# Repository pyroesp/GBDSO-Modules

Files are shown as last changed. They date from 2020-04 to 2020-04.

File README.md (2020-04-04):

# GBDSO Modules

This repository will include one or more schematics and PCBs based on the [GBDSO repository](https://github.com/pyroesp/GBDSO).  
In here I'll be making modules of the GBDSO schematic so that I can test them individually.  

A motherboard PCB will also be made so that all modules can be attached to each other and tested as a whole.  

Not sure yet how I'm going to set this up, but I'd like to keep everything related to the modules and motherboard in this repository.

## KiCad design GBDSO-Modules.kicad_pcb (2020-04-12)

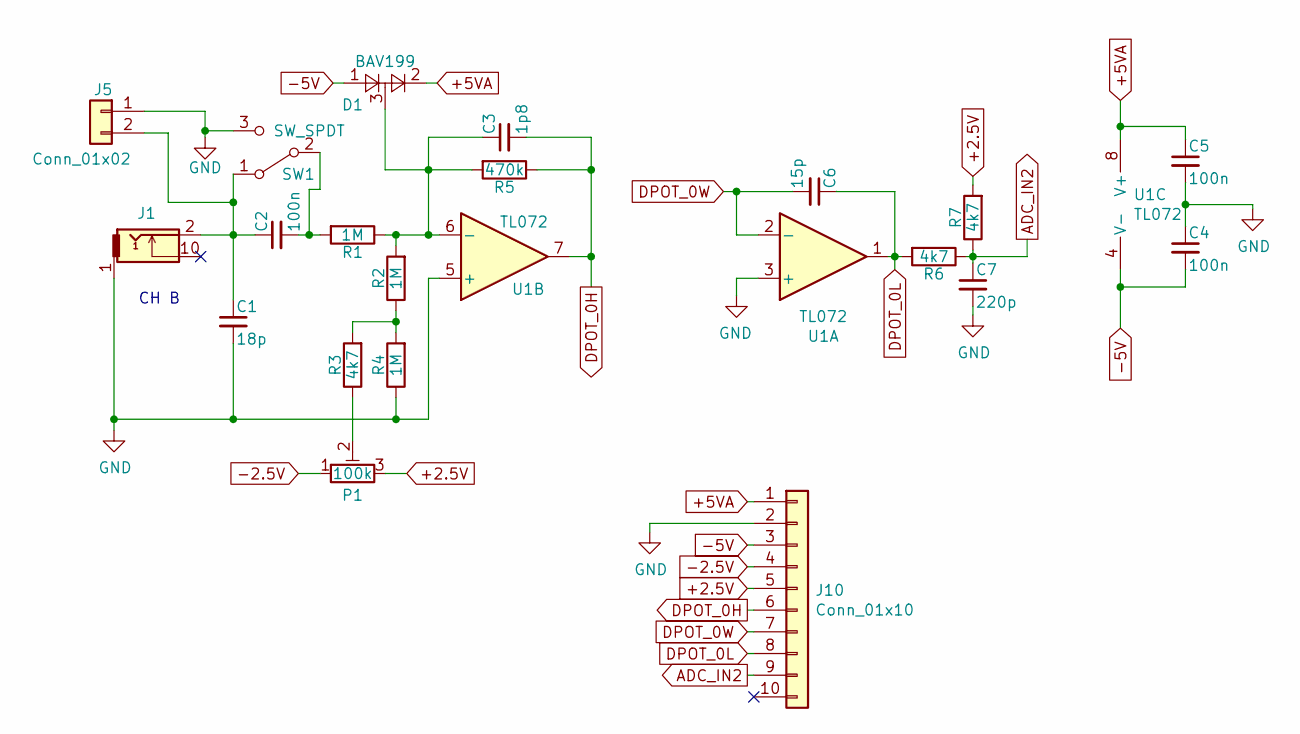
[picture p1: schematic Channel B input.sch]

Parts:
C1: 18p; C_0805_2012Metric
C2, C4, C5: 100n; C_0805_2012Metric
C3: 1p8; C_0805_2012Metric
C6: 15p; C_0805_2012Metric
C7: 220p; C_0805_2012Metric
D1: BAV199; SOT-23_Handsoldering
J1: MJ-3523-SMT-TR
J5: Conn_01x02; PinHeader_1x02_P2.54mm_Horizontal
J10: Conn_01x10; DIP-10_W10.16mm
P1: 100k; Potentiometer_Vishay_TS53YJ_Vertical
R1, R2, R4: 1M; R_0805_2012Metric
R3, R6, R7: 4k7; R_0805_2012Metric
R5: 470k; R_0805_2012Metric
SW1: SW_SPDT; SW_SPDT_CK-JS102011SAQN
U1: TL072; SOIC-8_3.9x4.9mm_P1.27mm

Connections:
+2.5V: J10.5, P1.3, R7.2; also elsewhere on the board
+5VA: C5.1, D1.2, J10.1, U1.8 (V+); also elsewhere on the board
-2.5V: J10.4, P1.1; also elsewhere on the board
-5V: C4.2, D1.1, J10.3, U1.4 (V-); also elsewhere on the board
ADC_IN2: C7.1, J10.9, R6.1, R7.1; also elsewhere on the board
DPOT_0H: C3.2, J10.6, R5.1, U1.7; also elsewhere on the board
DPOT_0L: C6.1, J10.8, R6.2, U1.1; also elsewhere on the board
DPOT_0W: C6.2, J10.7, U1.2 (-); also elsewhere on the board
GND: C1.2, C4.1, C5.2, C7.2, J1.1, J5.1, J10.2, R4.1, SW1.3 (C), U1.3 (+), U1.5 (+); also elsewhere on the board
unnamed: C1.1, C2.1, J1.2, J5.2, SW1.1 (A)
unnamed: C2.2, R1.2, SW1.2 (B)
unnamed: C3.1, D1.3, R1.1, R2.2, R5.2, U1.6 (-)
unnamed: P1.2, R3.1
unnamed: R2.1, R3.2, R4.2

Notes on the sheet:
CH B

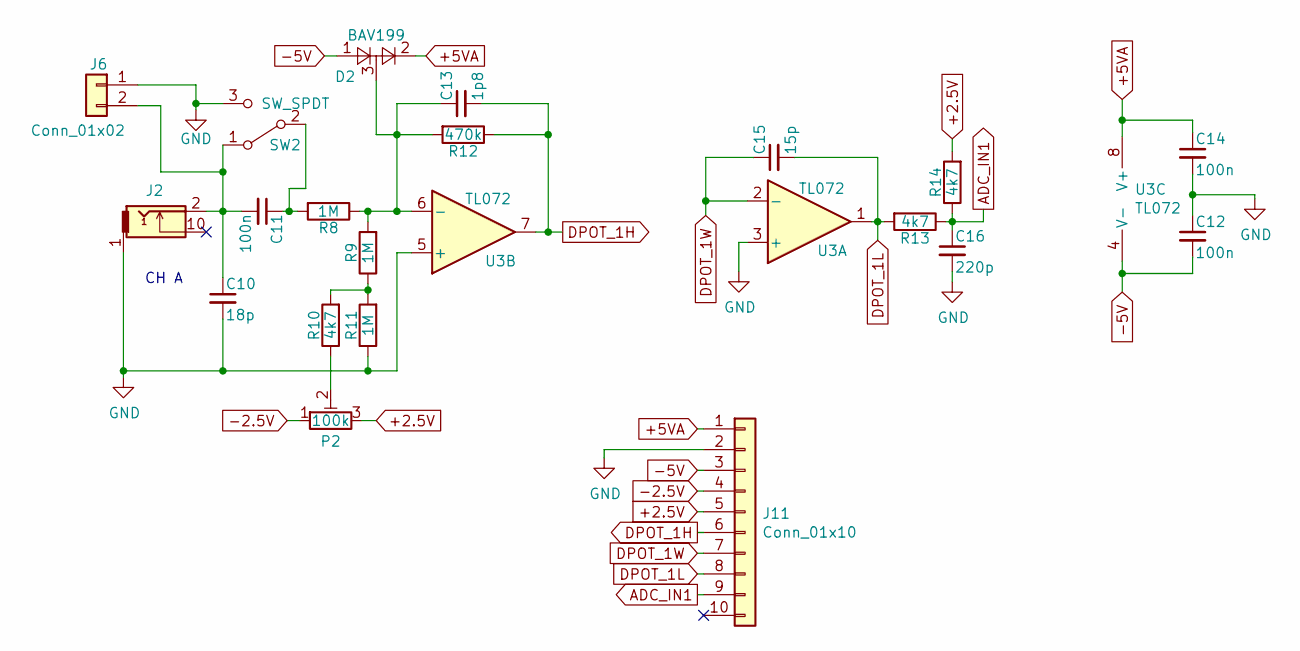
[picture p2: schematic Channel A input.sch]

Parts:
C10: 18p; C_0805_2012Metric
C11, C12, C14: 100n; C_0805_2012Metric
C13: 1p8; C_0805_2012Metric
C15: 15p; C_0805_2012Metric
C16: 220p; C_0805_2012Metric
D2: BAV199; SOT-23_Handsoldering
J2: MJ-3523-SMT-TR
J6: Conn_01x02; PinHeader_1x02_P2.54mm_Horizontal
J11: Conn_01x10; DIP-10_W10.16mm
P2: 100k; Potentiometer_Vishay_TS53YJ_Vertical
R8, R9, R11: 1M; R_0805_2012Metric
R10, R13, R14: 4k7; R_0805_2012Metric
R12: 470k; R_0805_2012Metric
SW2: SW_SPDT; SW_SPDT_CK-JS102011SAQN
U3: TL072; SOIC-8_3.9x4.9mm_P1.27mm

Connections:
+2.5V: J11.5, P2.3, R14.2; also elsewhere on the board
+5VA: C14.1, D2.2, J11.1, U3.8 (V+); also elsewhere on the board
-2.5V: J11.4, P2.1; also elsewhere on the board
-5V: C12.2, D2.1, J11.3, U3.4 (V-); also elsewhere on the board
ADC_IN1: C16.1, J11.9, R13.1, R14.1; also elsewhere on the board
DPOT_1H: C13.2, J11.6, R12.1, U3.7; also elsewhere on the board
DPOT_1L: C15.2, J11.8, R13.2, U3.1; also elsewhere on the board
DPOT_1W: C15.1, J11.7, U3.2 (-); also elsewhere on the board
GND: C10.2, C12.1, C14.2, C16.2, J2.1, J6.1, J11.2, R11.1, SW2.3 (C), U3.3 (+), U3.5 (+); also elsewhere on the board
unnamed: C10.1, C11.2, J2.2, J6.2, SW2.1 (A)
unnamed: C11.1, R8.2, SW2.2 (B)
unnamed: C13.1, D2.3, R8.1, R9.2, R12.2, U3.6 (-)
unnamed: P2.2, R10.1
unnamed: R9.1, R10.2, R11.2

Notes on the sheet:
CH A

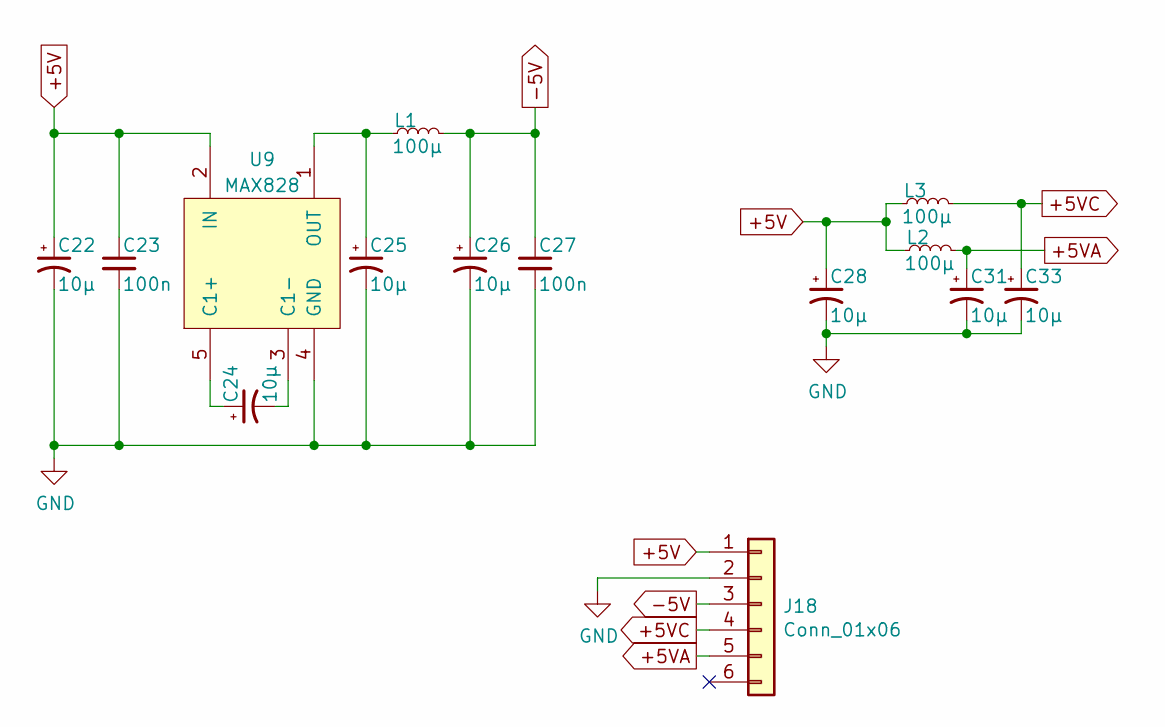
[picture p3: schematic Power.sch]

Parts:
C22, C24, C25, C26, C28, C31, C33: 10µ; C_1206_3216Metric
C23, C27: 100n; C_0805_2012Metric
J18: Conn_01x06; DIP-6_W7.62mm
L1, L2, L3: 100µ; L_0805_2012Metric_Pad1.15x1.40mm_HandSolder
U9: MAX828; SOT-23-5_HandSoldering

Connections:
+5V: C22.1, C23.1, C28.1, J18.1, L2.1, L3.1, U9.2 (IN); also elsewhere on the board
+5VA: C31.1, J18.5, L2.2; also elsewhere on the board
+5VC: C33.1, J18.4, L3.2; also elsewhere on the board
-5V: C26.1, C27.1, J18.3, L1.2; also elsewhere on the board
GND: C22.2, C23.2, C25.2, C26.2, C27.2, C28.2, C31.2, C33.2, J18.2, U9.4 (GND); also elsewhere on the board
unnamed: C24.1, U9.5 (C1+)
unnamed: C24.2, U9.3 (C1-)
unnamed: C25.1, L1.1, U9.1 (OUT)

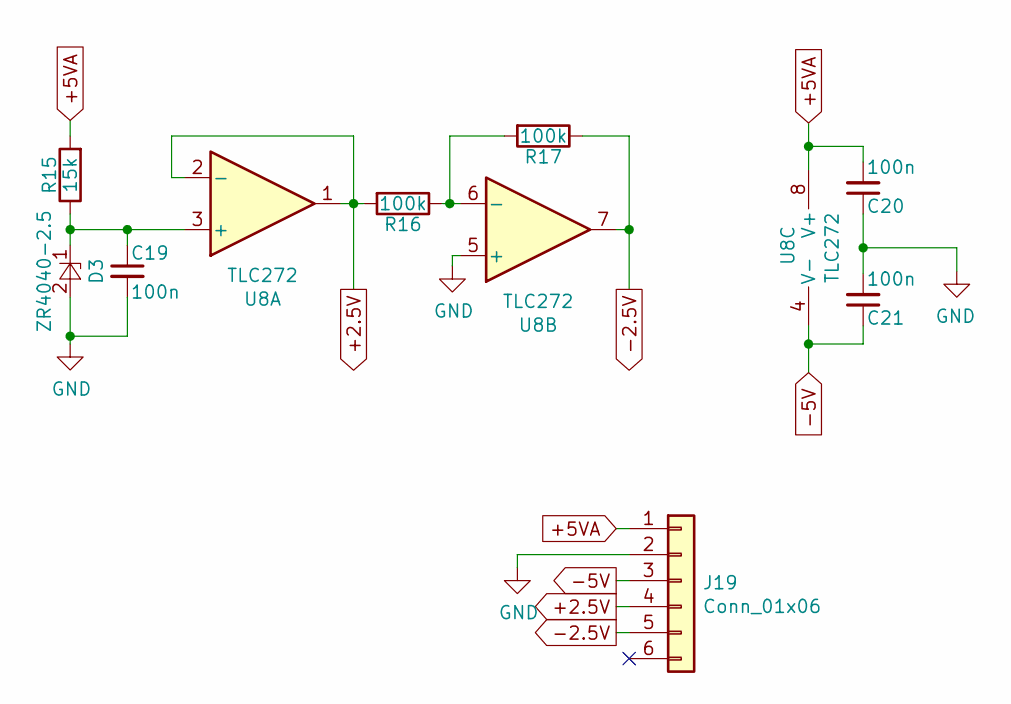
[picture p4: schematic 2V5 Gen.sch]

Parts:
C19, C20, C21: 100n; C_0805_2012Metric
D3: ZR4040-2.5; SOT-23_Handsoldering
J19: Conn_01x06; DIP-6_W10.16mm
R15: 15k; R_0805_2012Metric
R16, R17: 100k; R_0805_2012Metric
U8: TLC272; SOIC-8_3.9x4.9mm_P1.27mm

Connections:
+2.5V: J19.4, R16.2, U8.1, U8.2 (-); also elsewhere on the board
+5VA: C20.2, J19.1, R15.2, U8.8 (V+); also elsewhere on the board
-2.5V: J19.5, R17.1, U8.7; also elsewhere on the board
-5V: C21.1, J19.3, U8.4 (V-); also elsewhere on the board
GND: C19.2, C20.1, C21.2, D3.2, J19.2, U8.5 (+); also elsewhere on the board
unnamed: C19.1, D3.1, R15.1, U8.3 (+)
unnamed: R16.1, R17.2, U8.6 (-)

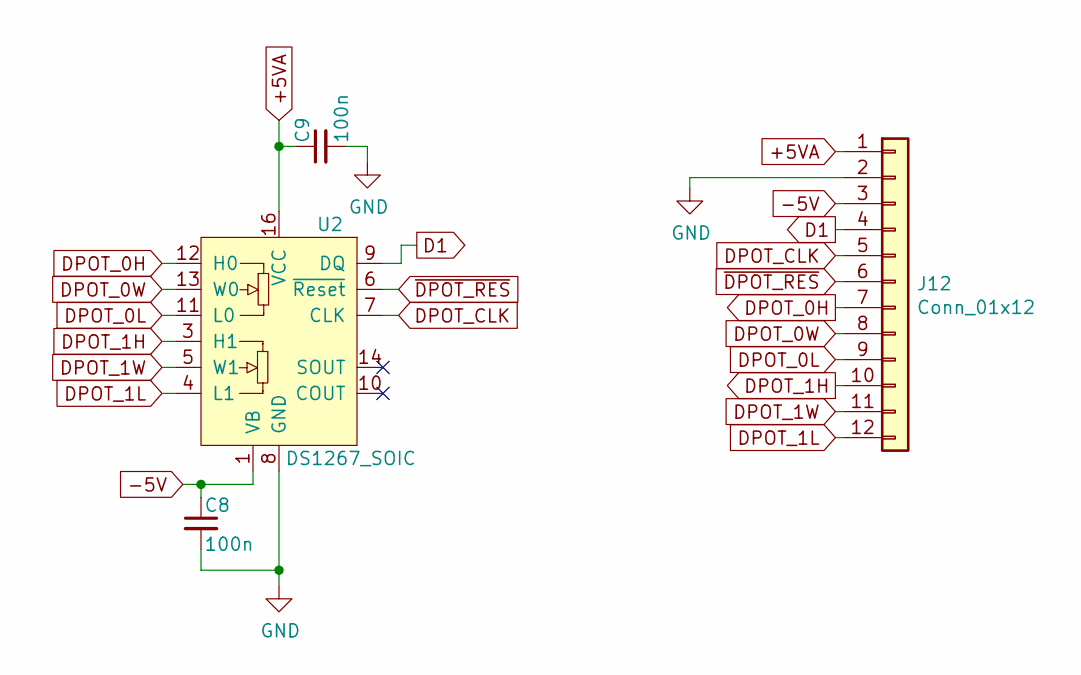
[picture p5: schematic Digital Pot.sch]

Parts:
C8, C9: 100n; C_0805_2012Metric
J12: Conn_01x12; PinHeader_1x12_P2.54mm_Vertical
U2: DS1267_SOIC; SOIC-16W_7.5x10.3mm_P1.27mm

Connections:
+5VA: C9.1, J12.1, U2.16 (VCC); also elsewhere on the board
-5V: C8.1, J12.3, U2.1 (VB); also elsewhere on the board
D1: J12.4, U2.9 (DQ); also elsewhere on the board
DPOT_0H: J12.7, U2.12 (H0); also elsewhere on the board
DPOT_0L: J12.9, U2.11 (L0); also elsewhere on the board
DPOT_0W: J12.8, U2.13 (W0); also elsewhere on the board
DPOT_1H: J12.10, U2.3 (H1); also elsewhere on the board
DPOT_1L: J12.12, U2.4 (L1); also elsewhere on the board
DPOT_1W: J12.11, U2.5 (W1); also elsewhere on the board
DPOT_CLK: J12.5, U2.7 (CLK); also elsewhere on the board
GND: C8.2, C9.2, J12.2, U2.8 (GND); also elsewhere on the board
~DPOT_RES: J12.6, U2.6 (~Reset); also elsewhere on the board

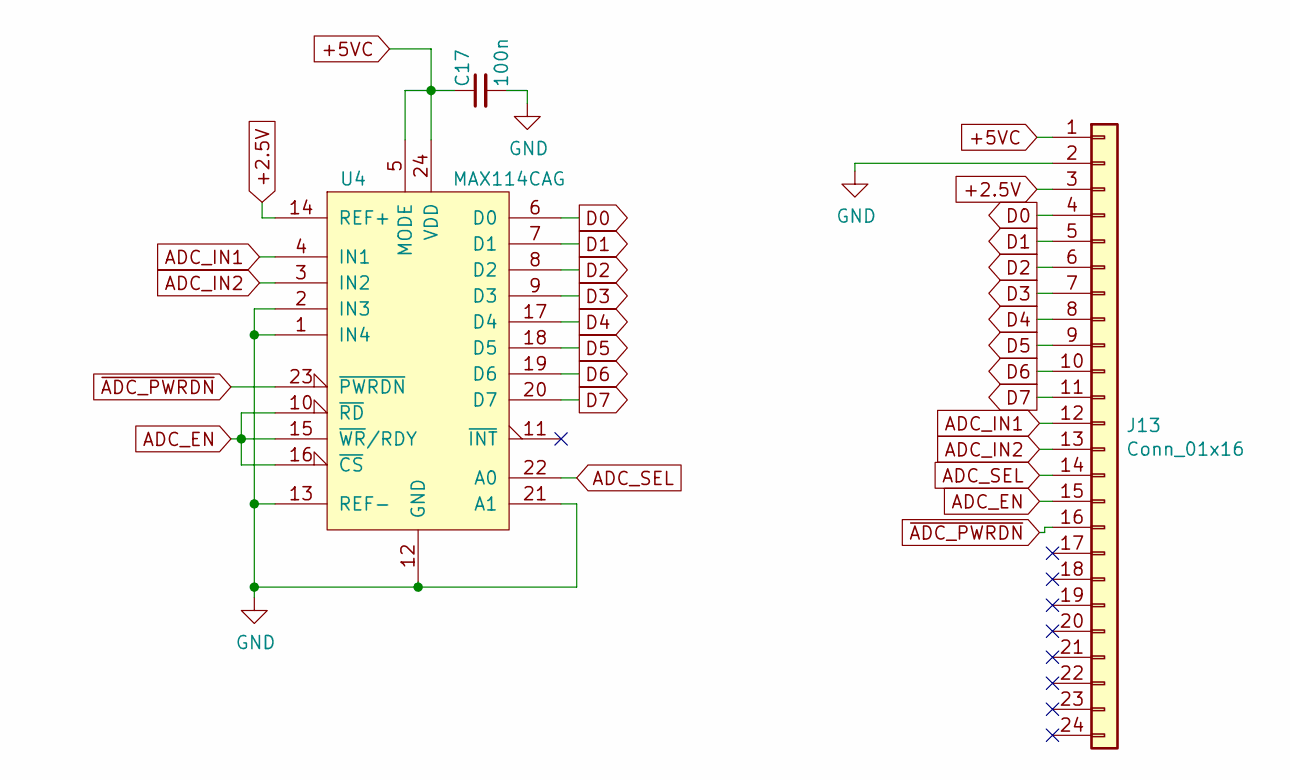
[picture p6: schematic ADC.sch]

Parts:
C17: 100n; C_0805_2012Metric
J13: Conn_01x16; DIP-24_W15.24mm
U4: MAX114CAG; SSOP-24_5.3x8.2mm_P0.65mm

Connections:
+2.5V: J13.3, U4.14 (REF+); also elsewhere on the board
+5VC: C17.1, J13.1, U4.5 (MODE), U4.24 (VDD); also elsewhere on the board
ADC_EN: J13.15, U4.10 (~RD), U4.15 (~WR~/RDY), U4.16 (~CS); also elsewhere on the board
ADC_IN1: J13.12, U4.4 (IN1); also elsewhere on the board
ADC_IN2: J13.13, U4.3 (IN2); also elsewhere on the board
ADC_SEL: J13.14, U4.22 (A0); also elsewhere on the board
D0: J13.4, U4.6 (D0); also elsewhere on the board
D1: J13.5, U4.7 (D1); also elsewhere on the board
D2: J13.6, U4.8 (D2); also elsewhere on the board
D3: J13.7, U4.9 (D3); also elsewhere on the board
D4: J13.8, U4.17 (D4); also elsewhere on the board
D5: J13.9, U4.18 (D5); also elsewhere on the board
D6: J13.10, U4.19 (D6); also elsewhere on the board
D7: J13.11, U4.20 (D7); also elsewhere on the board
GND: C17.2, J13.2, U4.1 (IN4), U4.2 (IN3), U4.12 (GND), U4.13 (REF-), U4.21 (A1); also elsewhere on the board
~ADC_PWRDN: J13.16, U4.23 (~PWRDN); also elsewhere on the board

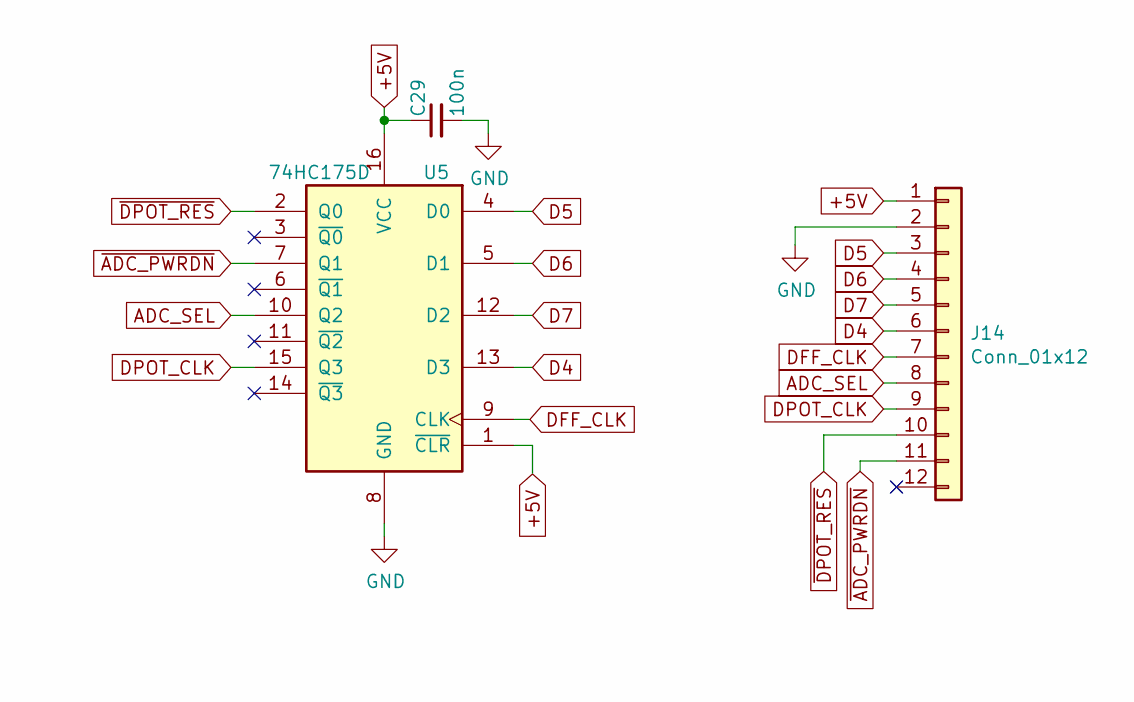
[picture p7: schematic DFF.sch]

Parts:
C29: 100n; C_0805_2012Metric
J14: Conn_01x12; DIP-12_W10.16mm_LongPads
U5: 74HC175D; SOIC-16_3.9x9.9mm_P1.27mm

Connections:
+5V: C29.1, J14.1, U5.1 (~CLR), U5.16 (VCC); also elsewhere on the board
ADC_SEL: J14.8, U5.10 (Q2); also elsewhere on the board
D4: J14.6, U5.13 (D3); also elsewhere on the board
D5: J14.3, U5.4 (D0); also elsewhere on the board
D6: J14.4, U5.5 (D1); also elsewhere on the board
D7: J14.5, U5.12 (D2); also elsewhere on the board
DFF_CLK: J14.7, U5.9 (CLK); also elsewhere on the board
DPOT_CLK: J14.9, U5.15 (Q3); also elsewhere on the board
GND: C29.2, J14.2, U5.8 (GND); also elsewhere on the board
~ADC_PWRDN: J14.11, U5.7 (Q1); also elsewhere on the board
~DPOT_RES: J14.10, U5.2 (Q0); also elsewhere on the board

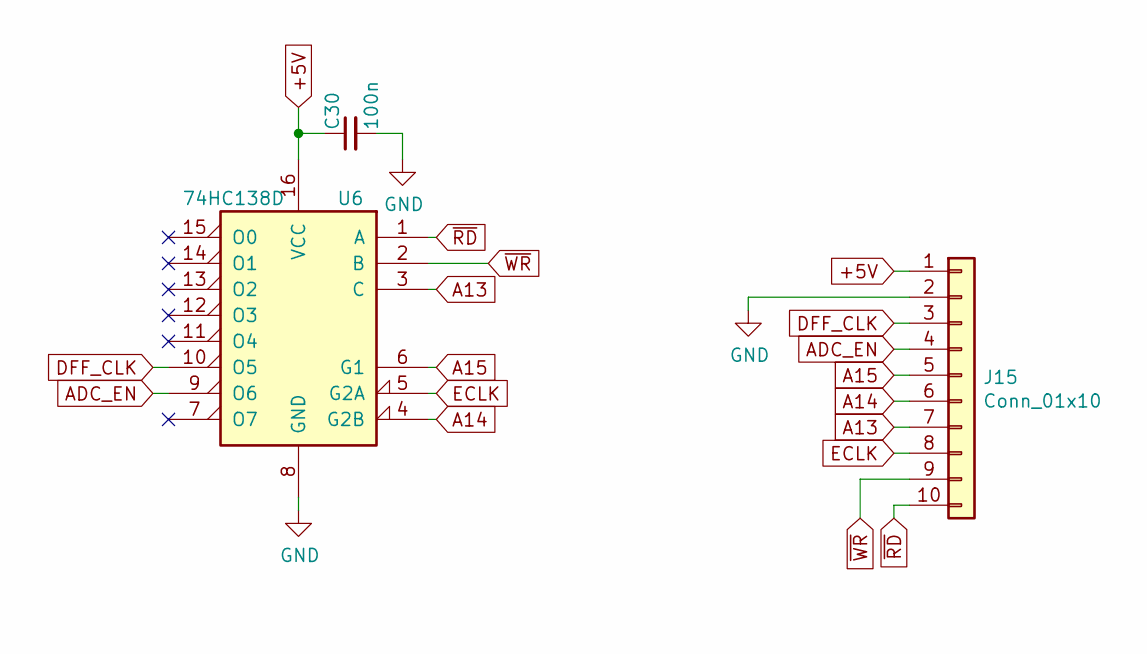
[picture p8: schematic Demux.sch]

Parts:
C30: 100n; C_0805_2012Metric
J15: Conn_01x10; DIP-10_W10.16mm
U6: 74HC138D; SOIC-16_3.9x9.9mm_P1.27mm

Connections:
+5V: C30.1, J15.1, U6.16 (VCC); also elsewhere on the board
A13: J15.7, U6.3 (C); also elsewhere on the board
A14: J15.6, U6.4 (G2B); also elsewhere on the board
A15: J15.5, U6.6 (G1); also elsewhere on the board
ADC_EN: J15.4, U6.9 (O6); also elsewhere on the board
DFF_CLK: J15.3, U6.10 (O5); also elsewhere on the board
ECLK: J15.8, U6.5 (G2A); also elsewhere on the board
GND: C30.2, J15.2, U6.8 (GND); also elsewhere on the board
~RD: J15.10, U6.1 (A); also elsewhere on the board
~WR: J15.9, U6.2 (B); also elsewhere on the board

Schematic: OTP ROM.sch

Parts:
C18: 100n; C_0805_2012Metric
J16: Conn_01x28; DIP-28_W7.62mm
JP1: SolderJumper_3_Open; SolderJumper-3_P1.3mm_Open_RoundedPad1.0x1.5mm_NumberLabels
U7: AT27C256R; PLCC-32_HandSolder

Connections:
+5V: C18.1, J16.1, JP1.3 (B), U7.32 (VCC); also elsewhere on the board
A0: J16.5, U7.11 (A0); also elsewhere on the board
A1: J16.6, U7.10 (A1); also elsewhere on the board
A2: J16.7, U7.9 (A2); also elsewhere on the board
A3: J16.8, U7.8 (A3); also elsewhere on the board
A4: J16.9, U7.7 (A4); also elsewhere on the board
A5: J16.10, U7.6 (A5); also elsewhere on the board
A6: J16.11, U7.5 (A6); also elsewhere on the board
A7: J16.12, U7.4 (A7); also elsewhere on the board
A8: J16.13, U7.29 (A8); also elsewhere on the board
A9: J16.14, U7.28 (A9); also elsewhere on the board
A10: J16.15, U7.24 (A10); also elsewhere on the board
A11: J16.16, U7.27 (A11); also elsewhere on the board
A12: J16.17, U7.3 (A12); also elsewhere on the board
A13: J16.18, U7.30 (A13); also elsewhere on the board
A14: J16.19, U7.31 (A14); also elsewhere on the board
A15: J16.20, U7.23 (~CE); also elsewhere on the board
D0: J16.21, U7.13 (D0); also elsewhere on the board
D1: J16.22, U7.14 (D1); also elsewhere on the board
D2: J16.23, U7.15 (D2); also elsewhere on the board
D3: J16.24, U7.18 (D3); also elsewhere on the board
D4: J16.25, U7.19 (D4); also elsewhere on the board
D5: J16.26, U7.20 (D5); also elsewhere on the board
D6: J16.27, U7.21 (D6); also elsewhere on the board
D7: J16.28, U7.22 (D7); also elsewhere on the board
GND: C18.2, J16.2, U7.16 (GND); also elsewhere on the board
unnamed: JP1.2 (C), U7.2 (VPP)
VPP: J16.4, JP1.1 (A); also elsewhere on the board
~RD: J16.3, U7.25 (~OE); also elsewhere on the board

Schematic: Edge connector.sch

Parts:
J3: Edge Connector; GB_EdgeConnector
J17: Conn_01x32; DIP-32_W7.62mm

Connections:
+5V: J3.1, J17.1; also elsewhere on the board
A0: J3.6, J17.7; also elsewhere on the board
A1: J3.7, J17.8; also elsewhere on the board
A2: J3.8, J17.9; also elsewhere on the board
A3: J3.9, J17.10; also elsewhere on the board
A4: J3.10, J17.11; also elsewhere on the board
A5: J3.11, J17.12; also elsewhere on the board
A6: J3.12, J17.13; also elsewhere on the board
A7: J3.13, J17.14; also elsewhere on the board
A8: J3.14, J17.15; also elsewhere on the board
A9: J3.15, J17.16; also elsewhere on the board
A10: J3.16, J17.17; also elsewhere on the board
A11: J3.17, J17.18; also elsewhere on the board
A12: J3.18, J17.19; also elsewhere on the board
A13: J3.19, J17.20; also elsewhere on the board
A14: J3.20, J17.21; also elsewhere on the board
A15: J3.21, J17.22; also elsewhere on the board
D0: J3.22, J17.23; also elsewhere on the board
D1: J3.23, J17.24; also elsewhere on the board
D2: J3.24, J17.25; also elsewhere on the board
D3: J3.25, J17.26; also elsewhere on the board
D4: J3.26, J17.27; also elsewhere on the board
D5: J3.27, J17.28; also elsewhere on the board
D6: J3.28, J17.29; also elsewhere on the board
D7: J3.29, J17.30; also elsewhere on the board
ECLK: J3.2, J17.3; also elsewhere on the board
GND: J3.32, J17.2; also elsewhere on the board
VPP: J3.5, J17.6; also elsewhere on the board
~RD: J3.4, J17.5; also elsewhere on the board
~WR: J3.3, J17.4; also elsewhere on the board

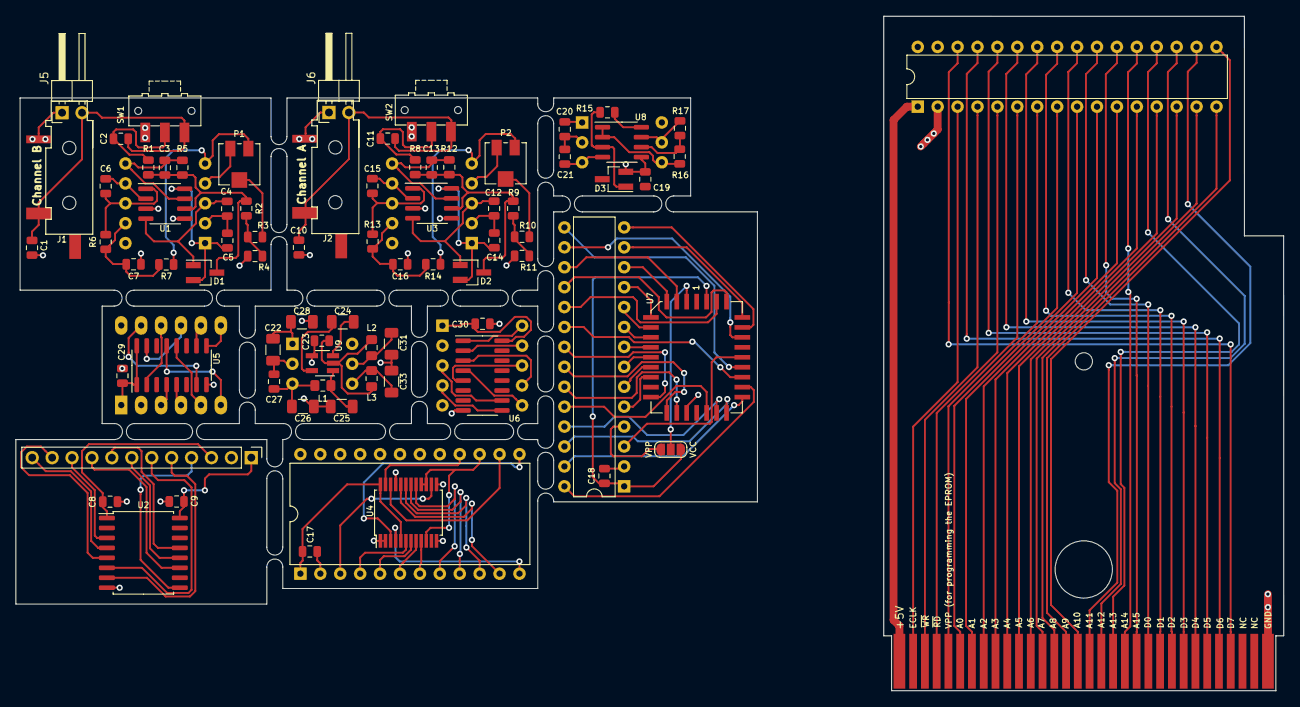
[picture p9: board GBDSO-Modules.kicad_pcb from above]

Board: 2 copper layers, 94.6 x 64.5 mm, 84 parts (0 on the bottom side), 65 nets.

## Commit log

2020-04-04 setting up this repo with files from the GBDSO repo
    setup kicad project, copied schematic, copied components
    [GBDSO-Modules.kicad_pcb, GBDSO-Modules.sch]
2020-04-04 separated each module into a different sheet, started the pcb
    [2V5 Gen.sch, ADC.sch, Channel A input.sch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]
2020-04-04 C8 on the dig pot wasn't connected correctly
    changed the schematic, updated the netlist and PCB
    [Digital Pot.sch, GBDSO-Modules.kicad_pcb]
2020-04-05 fixed schematic and updated PCB
    Fixed the schematic after having found the issues in the GBDSO schematic (which is also fixed on the repo).
    Continued making the PCB for the modules. We're not at 7 modules from 10.
    [2V5 Gen.sch, ADC.sch, Channel A input.sch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]
2020-04-12 added the PLCC32 handsolder footprint I made on the other repo here
    [OTP ROM.sch]
2020-04-12 pin 10 of J12 was not connected to the correct signal, fixed
    [Digital Pot.sch]
2020-04-12 Finished and panelized the PCBs, except for edge connector; too big
    [GBDSO-Modules.kicad_pcb]
2020-04-12 forgot to add the ground plane on the panel, fixed
    [GBDSO-Modules.kicad_pcb]
